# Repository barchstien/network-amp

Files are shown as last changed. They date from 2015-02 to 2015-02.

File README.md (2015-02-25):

# network-amp
PCB including DAC, audio amp, RaspberryPi interface and power supply

<br /><span xmlns:dct="http://purl.org/dc/terms/" property="dct:title">network-amp</span> by <span xmlns:cc="http://creativecommons.org/ns#" property="cc:attributionName">bastienauneau</span> is licensed under a <a rel="license" href="http://creativecommons.org/licenses/by-sa/4.0/">Creative Commons Attribution-ShareAlike 4.0 International License</a>.

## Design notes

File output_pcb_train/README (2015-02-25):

All files have been generated by KiCAD (specified if modified)

For any question, please contact:
Bastien Auneau
bastien.auneau@gmail.com
+33 7 81 13 59 88

## PCB ##
_ audio_pi.drl
    drill file
_ audio_pi-B_Cu.gbr 
_ audio_pi-B_Mask.gbr
_ audio_pi-drl_map.gbr
    drill diameter map (useless ?)
_ audio_pi-Edge_Cuts.gbr
_ audio_pi-F_Cu.gbr
_ audio_pi-F_Mask.gbr
_ audio_pi-F_Paste.gbr
_ audio_pi-F_SilkS.gbr

## ASSEMBLY ##
_ audio_pi-all_position.csv
    smd components position, based on kicad generated "footprint position .pos file"
    joined with BOM file for SUPPLIER and SUPPLIER PART NO. columns
_ audio_pi_BOM.csv
    BOM, ordered by value after generation by kicad

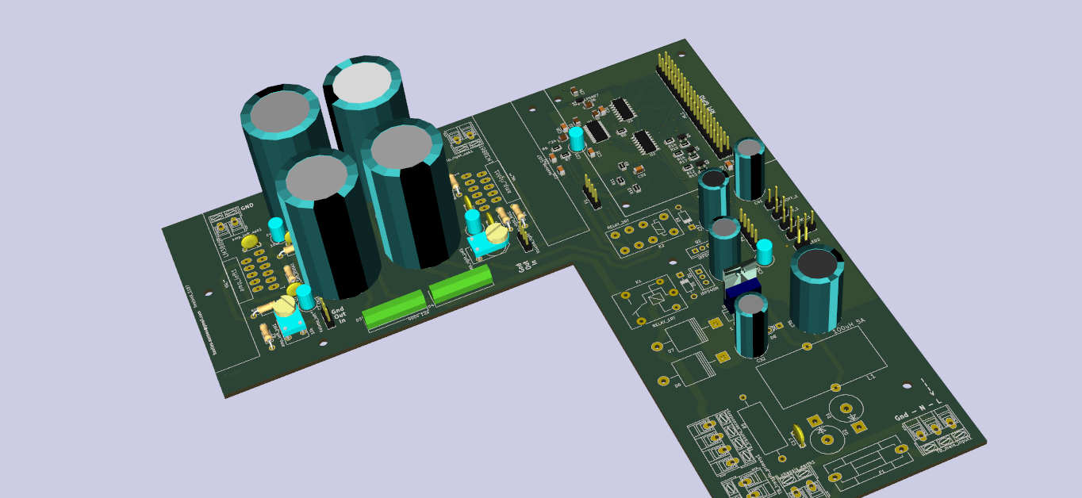
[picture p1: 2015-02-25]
audio_pi_3d.png

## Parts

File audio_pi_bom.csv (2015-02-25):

Reference | Value | Footprint | Datasheet | e44.com | SUPPLIER | SUPPLIER PART NO. | Comment
amp_left1 | LM3886T | lib:TO220-11 |  | LM3886T
U1 | PCM5122 | Housings_SSOP:TSSOP-28_4.4x9.7mm_Pitch0.65mm |  |  | Farnell | 2307931
R2 | 10k | Resistors_ThroughHole:Resistor_Horizontal_RM10mm |  | MA10K0
C8 | 100nf | Capacitors_ThroughHole:Capacitor6MMDiscRM5 |  | CC5100NF
C3 | 100nf | Capacitors_ThroughHole:Capacitor6MMDiscRM5 |  | CC5100NF
C4 | 10uf | Discret:C1V7 |  | CHR10100
C7 | 10uf | Discret:C1V7 |  | CHR10100
amp_left_pot1 | 10k | Discret:RV2X4 |  | CA9V10K
amp_left_spk1 | Terminal_block_2 | Connect:AK300-2 |  | SCREW02BL
C2 | 220pf | Capacitors_ThroughHole:Capacitor6MMDiscRM5 |  | CC5220PF/500
R1 | 1k | Resistors_ThroughHole:Resistor_Horizontal_RM10mm |  | MA1K0
amp_left_Rfdbk1 | 20k | Resistors_ThroughHole:Resistor_Horizontal_RM10mm |  | MA20K0
amp_left_Rin1 | 1k | Resistors_ThroughHole:Resistor_Horizontal_RM10mm |  | MA1K0
R4 | 10k | Resistors_ThroughHole:Resistor_Horizontal_RM10mm |  | MA10K0
C16 | 100nf | Capacitors_ThroughHole:Capacitor6MMDiscRM5 |  | CC5100NF
C11 | 100nf | Capacitors_ThroughHole:Capacitor6MMDiscRM5 |  | CC5100NF
C15 | 10uf | Discret:C1V7 |  | CHR10100
amp_right_pot1 | 10k | Discret:RV2X4 |  | CA9V10K
amp_right_spk1 | Terminal_block_2 | Connect:AK300-2 |  | SCREW02BL
C10 | 220pf | Capacitors_ThroughHole:Capacitor6MMDiscRM5 |  | CC5220PF/500
R3 | 1k | Resistors_ThroughHole:Resistor_Horizontal_RM10mm |  | MA1K0
amp_right_Rfdbk1 | 20k | Resistors_ThroughHole:Resistor_Horizontal_RM10mm |  | MA20K0
amp_right_Rin1 | 1k | Resistors_ThroughHole:Resistor_Horizontal_RM10mm |  | MA1K0
TB_main_input1 | Terminal_block_3 | Connect:AK300-3 |  | SCREW03BL
C17 | 100nf | Capacitors_ThroughHole:Capacitor6MMDiscRM5 |  | CCM100NF
D2 | 400v 6a p6 | Diodes_ThroughHole:Diode_P600_Vertical_KathodeUp |  | P600G
D1 | 400v 6a p6 | Diodes_ThroughHole:Diode_P600_Vertical_KathodeUp |  | P600G
R5 | 10_5W | Resistors_ThroughHole:Resistor_Horizontal_RM25mm |  | vrac
TB_transfo_primary1 | Terminal_block_2 | Connect:AK300-2 |  | SCREW02BL
TB_transfo_secondary1 | Terminal_block_4 | Connect:AK300-4 |  | 2xSCREW02BL
D4 | 400v 12a | Connect:bornier4 |  | KBU12G
D3 | 400v 12a | Connect:bornier4 |  | KBU12G
C18 | 4700uF | Capacitors_ThroughHole:Capacitor26x45RM10 |  | CHR470080-85
C28 | 4700uF | Capacitors_ThroughHole:Capacitor26x45RM10 |  | CHR470080-85
C19 | 4700uF | Capacitors_ThroughHole:Capacitor26x45RM10 |  | CHR470080-85
C29 | 4700uF | Capacitors_ThroughHole:Capacitor26x45RM10 |  | CHR470080-85
U4 | LM2576-5.0 | Pentawatts:Pentawatt_Neutral_Staggered_Verical_TO220-5-T05D |  | LM2576T5
C32 | 100uf | Capacitors_ThroughHole:Capacitor10x21RM5 |  | CHR100100
D8 | 1N5822 | Diodes_ThroughHole:Diode_DO-41_SOD81_Vertical_KathodeUp |  | 1N5822
C35 | 2200uf | Capacitors_ThroughHole:Capacitor16x25RM7.5 |  | CHR220035
L1 | 100uH 5A | lib:inductance |  | HFSECO5/100
U5 | LP5907 | SMD_Packages:SOT-23-5 |  |  | Digikey | 296-38557-1-ND
K2 | RELAY_2RT | lib:Relais_double |  | F3022-5
K1 | RELAY_1RT | lib:Relay_Power |  | F3611-5
Q1 | IRF540N | Discret:TO220_VERT |  | IRF540NPBF
Q2 | IRF540N | Discret:TO220_VERT |  | IRF540NPBF
P2 | Volume_left | Pin_Headers:Pin_Header_Straight_1x03 |  | BTWM3
P3 | Volume_right | Pin_Headers:Pin_Header_Straight_1x03 |  | BTWM3
C37 | 100uf | Capacitors_ThroughHole:Capacitor10x21RM5 |  | CHR100100
D9 | TVS 1500w 400v do201 | Diodes_ThroughHole:Diode_DO-41_SOD81_Horizontal_RM10 |  | 1.5KE400CA
D5 | TVS 1500w 400v do201 | Diodes_ThroughHole:Diode_DO-41_SOD81_Horizontal_RM10 |  | 1.5KE400CA
C27 | 100uf | Capacitors_ThroughHole:Capacitor10x21RM5 |  | CHR100100
D6 | 400v 6a p6 | Diodes_ThroughHole:Diode_P600_Horizontal |  | P600G
D7 | 400v 6a p6 | Diodes_ThroughHole:Diode_P600_Horizontal |  | P600G
F1 | 5A | Fuse_Holders_and_Fuses:Fuseholder5x20_horiz_SemiClosed_Casing10x25mm |  | FUSE/HL*
TB_chassis_earth1 | Terminal_block_2 | Connect:AK300-2 |  | SCREW02BL
C22 | 0.1uf | Capacitors_SMD:C_1206 |  |  | Farnell | 1759361 | PCB Train free component stock
C34 | 1uf | Capacitors_SMD:C_1206 |  |  | Farnell | 1759454 | PCB Train free component stock
C26 | 2.2uf | Capacitors_SMD:C_1206 |  |  | Farnell | 2310423 | PCB Train free component stock
C24 | 2.2uf | Capacitors_SMD:C_1206 |  |  | Farnell | 2310423 | PCB Train free component stock
R6 | 470R | Resistors_SMD:R_1206 |  |  | Farnell | 2129621 | PCB Train free component stock
R7 | 470R | Resistors_SMD:R_1206 |  |  | Farnell | 2129621 | PCB Train free component stock
C20 | 2.2nf | Capacitors_SMD:C_1206 |  |  | Farnell | 1759341 | PCB Train free component stock
C23 | 10uf | Discret:C1V7 |  | CHR10100
C30 | 0.1uf | Capacitors_SMD:C_1206 |  |  | Farnell | 1759361 | PCB Train free component stock
C31 | 0.1uf | Capacitors_SMD:C_1206 |  |  | Farnell | 1759361 | PCB Train free component stock
R8 | 10k | Resistors_SMD:R_1206 |  |  | Farnell | 2129728 | PCB Train free component stock
U2 | IL717 | Housings_SOIC:SOIC-16_3.9x9.9mm_Pitch1.27mm |  |  | Farnell | 9570659
P1 | CONN_01X04 | Pin_Headers:Pin_Header_Straight_1x04 |  | header pin
R10 | 47k | Resistors_SMD:R_1206 |  |  | Farnell | 2129783 | PCB Train free component stock
R9 | 100k | Resistors_SMD:R_1206 |  |  | Farnell | 2129810 | PCB Train free component stock
R11 | 10k | Resistors_SMD:R_1206 |  |  | Farnell | 2129728 | PCB Train free component stock
C33 | 10nf | Capacitors_SMD:C_1206 |  |  | Farnell | 1759350 | PCB Train free component stock
C12 | 10uf | Discret:C1V7 |  | CHR10100
C36 | 1uf | Capacitors_SMD:C_1206 |  |  | Farnell | 1759454 | PCB Train free component stock
C25 | 0.1uf | Capacitors_SMD:C_1206 |  |  | Farnell | 1759361 | PCB Train free component stock
C21 | 2.2nf | Capacitors_SMD:C_1206 |  |  | Farnell | 1759341 | PCB Train free component stock
U3 | IL715 | Housings_SOIC:SOIC-16_3.9x9.9mm_Pitch1.27mm |  |  | Farnell | 9570632
amp_right1 | LM3886T | lib:TO220-11 |  | LM3886T
C9 | 22uf | Capacitors_ThroughHole:Capacitor8x13RM3.8 |  | CHR22100
C1 | 22uf | Capacitors_ThroughHole:Capacitor8x13RM3.8 |  | CHR22100
Q3 | MMBF170 | SMD_Packages:SOT-23 |  |  | Farnell | 9845399
Q4 | MMBF170 | SMD_Packages:SOT-23 |  |  | Farnell | 9845399
Q5 | MMBF170 | SMD_Packages:SOT-23 |  |  | Farnell | 9845399
R12 | 10k | Resistors_SMD:R_1206 |  |  | Farnell | 2129728 | PCB Train free component stock
R13 | 10k | Resistors_SMD:R_1206 |  |  | Farnell | 2129728 | PCB Train free component stock
R14 | 10k | Resistors_SMD:R_1206 |  |  | Farnell | 2129728 | PCB Train free component stock
R15 | 10k | Resistors_SMD:R_1206 |  |  | Farnell | 2129728 | PCB Train free component stock
R17 | 10k | Resistors_SMD:R_1206 |  |  | Farnell | 2129728 | PCB Train free component stock
R16 | 10k | Resistors_SMD:R_1206 |  |  | Farnell | 2129728 | PCB Train free component stock
C38 | 10uf | Discret:C1V7 |  | CHR10100
FAV_1 | CONN_01X02 | Pin_Headers:Pin_Header_Straight_1x02 |  | BTWM2
U6 | LP5907 | SMD_Packages:SOT-23-5 |  |  | Digikey | 296-38557-1-ND
C39 | 1uf | Resistors_SMD:R_1206 |  |  | Farnell | 1759454 | PCB Train free component stock
C40 | 1uf | Resistors_SMD:R_1206 |  |  | Farnell | 1759454 | PCB Train free component stock
ONOFF_1 | CONN_01X02 | Pin_Headers:Pin_Header_Straight_1x02 |  | BTWM2
J8_1 | RPI_B+_J8_header | Pin_Headers:Pin_Header_Straight_2x20
C41 | 100uf | Capacitors_ThroughHole:Capacitor10x21RM5 |  | CHR100100
C42 | 100nf | Capacitors_SMD:C_1206 |  |  | Farnell | 1759361 | PCB Train free component stock
PWM1_1 | CONN_01X02 | Pin_Headers:Pin_Header_Straight_1x02 |  | BTWM2
Q7 | IRF540N | Discret:TO220_VERT |  | IRF540NPBF
LED2 | CONN_01X02 | Pin_Headers:Pin_Header_Straight_1x02 |  | BTWM2
P4 | CONN_01X05 | Pin_Headers:Pin_Header_Straight_1x05
I2C1_1 | CONN_01X04 | Pin_Headers:Pin_Header_Straight_1x04

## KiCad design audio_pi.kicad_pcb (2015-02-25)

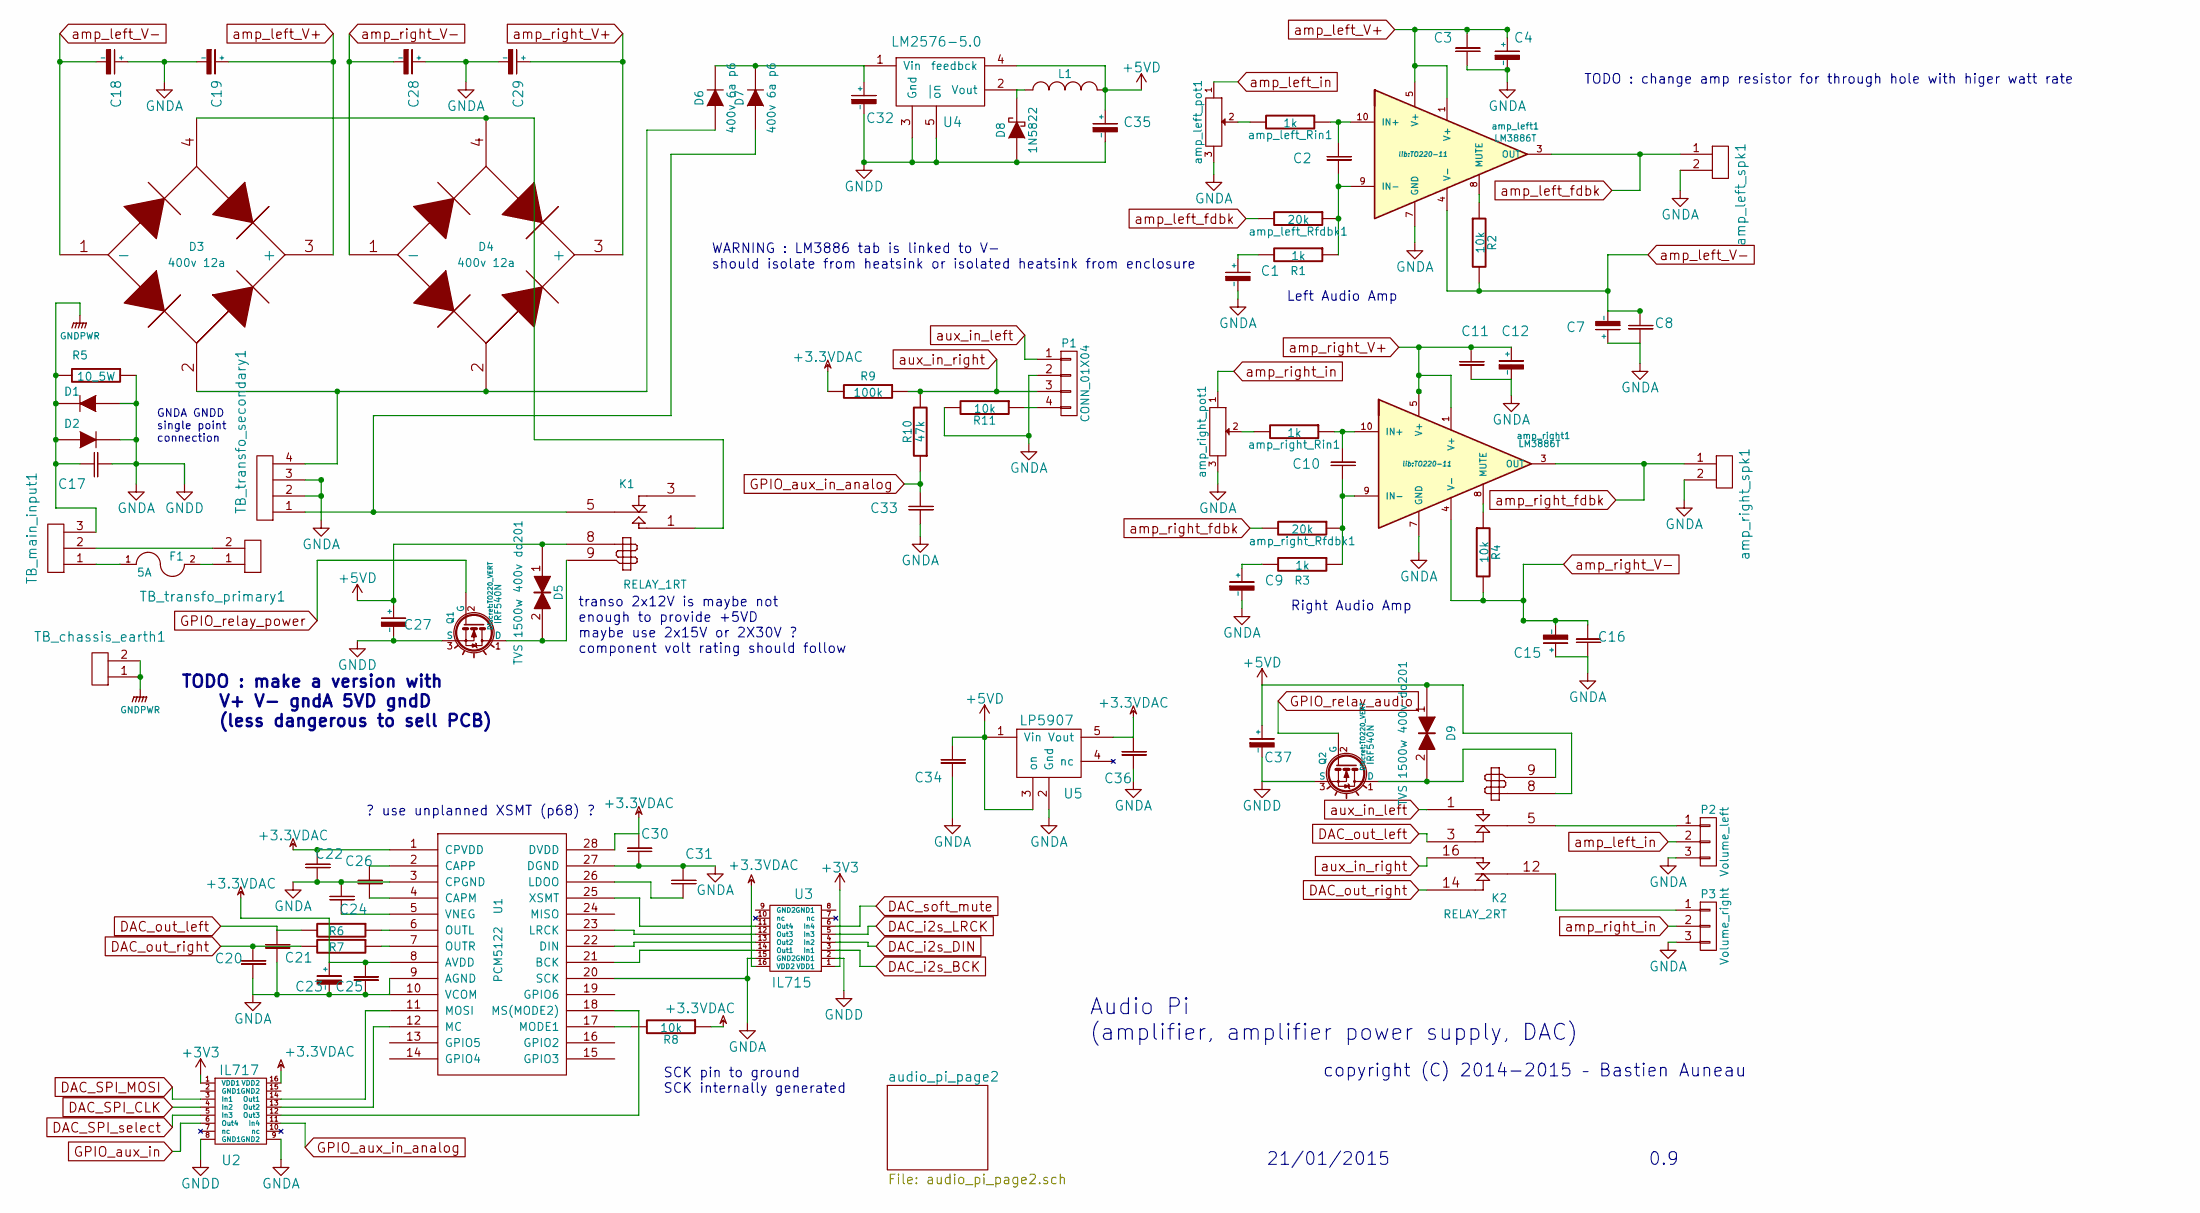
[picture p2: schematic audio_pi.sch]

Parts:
C1, C9: 22uf; Capacitor8x13RM3.8
C2, C10: 220pf; Capacitor6MMDiscRM5
C3, C8, C11, C16, C17: 100nf; Capacitor6MMDiscRM5
C4, C7, C12, C15, C23: 10uf; C1V7
C18, C19, C28, C29: 4700uF; Capacitor26x45RM10
C20, C21: 2.2nf; C_1206
C22, C25, C30, C31: 0.1uf; C_1206
C24, C26: 2.2uf; C_1206
C27, C32, C37: 100uf; Capacitor10x21RM5
C33: 10nf; C_1206
C34, C36: 1uf; C_1206
C35: 2200uf; Capacitor16x25RM7.5
D1, D2: 400v 6a p6; Diode_P600_Vertical_KathodeUp
D3, D4: 400v 12a; bornier4
D5, D9: TVS 1500w 400v do201; Diode_DO-41_SOD81_Horizontal_RM10
D6, D7: 400v 6a p6; Diode_P600_Horizontal
D8: 1N5822; Diode_DO-41_SOD81_Vertical_KathodeUp
F1: 5A; Fuseholder5x20_horiz_SemiClosed_Casing10x25mm
K1: RELAY_1RT; Relay_Power
K2: RELAY_2RT; Relais_double
L1: 100uH 5A; inductance
P1: CONN_01X04; Pin_Header_Straight_1x04
P2: Volume_left; Pin_Header_Straight_1x03
P3: Volume_right; Pin_Header_Straight_1x03
Q1, Q2: IRF540N; TO220_VERT
R1, R3: 1k; Resistor_Horizontal_RM10mm
R2, R4: 10k; Resistor_Horizontal_RM10mm
R5: 10_5W; Resistor_Horizontal_RM25mm
R6, R7: 470R; R_1206
R8, R11: 10k; R_1206
R9: 100k; R_1206
R10: 47k; R_1206
TB_chassis_earth1: Terminal_block_2; AK300-2
TB_main_input1: Terminal_block_3; AK300-3
TB_transfo_primary1: Terminal_block_2; AK300-2
TB_transfo_secondary1: Terminal_block_4; AK300-4
U1: PCM5122; TSSOP-28_4.4x9.7mm_Pitch0.65mm
U2: IL717; SOIC-16_3.9x9.9mm_Pitch1.27mm
U3: IL715; SOIC-16_3.9x9.9mm_Pitch1.27mm
U4: LM2576-5.0; Pentawatt_Neutral_Staggered_Verical_TO220-5-T05D
U5: LP5907; SOT-23-5
amp_left1: LM3886T; TO220-11
amp_left_Rfdbk1: 20k; Resistor_Horizontal_RM10mm
amp_left_Rin1: 1k; Resistor_Horizontal_RM10mm
amp_left_pot1: 10k; RV2X4
amp_left_spk1: Terminal_block_2; AK300-2
amp_right1: LM3886T; TO220-11
amp_right_Rfdbk1: 20k; Resistor_Horizontal_RM10mm
amp_right_Rin1: 1k; Resistor_Horizontal_RM10mm
amp_right_pot1: 10k; RV2X4
amp_right_spk1: Terminal_block_2; AK300-2

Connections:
+3.3VDAC: C22.2, C23.1 (+), C25.2, C30.2, C36.2, R8.1, R9.2, U1.1 (CPVDD), U1.8 (AVDD), U1.28 (DVDD), U2.16 (VDD2), U3.16 (VDD2), U5.5 (Vout)
+3V3: U2.1 (VDD1), U3.1 (VDD1); also elsewhere on the board
+5VD: C27.1 (+), C34.2, C35.1 (+), C37.1 (+), D5.1, D9.1, K1.8, K2.8, L1.2, U4.4 (feedbck), U5.1 (Vin), U5.3 (on); also elsewhere on the board
DAC_SPI_CLK: U2.4 (In2); also elsewhere on the board
DAC_SPI_select: U2.5 (In3); also elsewhere on the board
DAC_i2s_BCK: U3.3 (In1); also elsewhere on the board
DAC_i2s_DIN: U3.4 (In2); also elsewhere on the board
DAC_i2s_LRCK: U3.5 (In3); also elsewhere on the board
DAC_out_left: C21.2, K2.3 (R1), R6.2
DAC_out_right: C20.2, K2.14 (R2), R7.2
DAC_soft_mute: U3.6 (In4); also elsewhere on the board
GNDD: C1.2 (-), C3.1, C4.2 (-), C7.1 (+), C8.1, C9.2 (-), C11.1, C12.2 (-), C15.1 (+), C16.1, C17.2, C18.1 (+), C19.2 (-), C20.1, C21.1, C22.1, C23.2 (-), C24.2, C25.1, C27.2 (-), C28.1 (+), C29.2 (-), C30.1, C31.2, C32.2 (-), C33.1, C34.1, C35.2 (-), C36.1, C37.2 (-), D1.1 (A), D2.2 (K), D8.1 (A), P1.2, P2.3, P3.3, Q1.3 (S), Q2.3 (S), R5.1, R11.2, TB_transfo_secondary1.2, TB_transfo_secondary1.3, U1.3 (CPGND), U1.9 (AGND), U1.10 (VCOM), U1.20 (SCK), U1.27 (DGND), U2.8 (GND1), U2.9 (GND2), U3.2 (GND1), U3.15 (GND2), U4.3 (Gnd), U4.5 (~on), U5.2 (Gnd), amp_left1.7 (GND), amp_left_pot1.3, amp_left_spk1.2, amp_right1.7 (GND), amp_right_pot1.3, amp_right_spk1.2; also elsewhere on the board
GNDPWR: C17.1, D1.2 (K), D2.1 (A), R5.2, TB_chassis_earth1.1, TB_chassis_earth1.2, TB_main_input1.3
GPIO_aux_in: U2.6 (Out4); also elsewhere on the board
GPIO_aux_in_analog: C33.2, R10.1, U2.11 (In4)
GPIO_relay_audio: Q2.2 (G); also elsewhere on the board
GPIO_relay_power: Q1.2 (G); also elsewhere on the board
unnamed: C1.1 (+), R1.2
unnamed: C2.1, R1.1, amp_left1.9 (IN-), amp_left_Rfdbk1.1
unnamed: C2.2, amp_left1.10 (IN+), amp_left_Rin1.1
unnamed: C9.1 (+), R3.2
unnamed: C10.1, R3.1, amp_right1.9 (IN-), amp_right_Rfdbk1.1
unnamed: C10.2, amp_right1.10 (IN+), amp_right_Rin1.1
unnamed: C24.1, U1.5 (VNEG)
unnamed: C26.1, U1.4 (CAPM)
unnamed: C26.2, U1.2 (CAPP)
unnamed: C31.1, U1.26 (LDOO)
unnamed: C32.1 (+), D6.2 (K), D7.2 (K), U4.1 (Vin)
unnamed: D3.2, D4.2, D6.1 (A), TB_transfo_secondary1.4
unnamed: D3.4, D4.4, K1.1 (T1)
unnamed: D5.2, K1.9, Q1.1 (D)
unnamed: D7.1 (A), K1.5 (C1), TB_transfo_secondary1.1
unnamed: D8.2 (K), L1.1, U4.2 (Vout)
unnamed: D9.2, K2.9, Q2.1 (D)
unnamed: F1.1, TB_main_input1.1
unnamed: F1.2, TB_transfo_primary1.1
unnamed: K2.5 (C1), P2.1
unnamed: K2.12 (C2), P3.1
unnamed: P1.4, R11.1
unnamed: R2.1, amp_left1.8 (MUTE)
unnamed: R4.1, amp_right1.8 (MUTE)
unnamed: R6.1, U1.6 (OUTL)
unnamed: R7.1, U1.7 (OUTR)
unnamed: R8.2, U1.17 (MODE1)
unnamed: TB_main_input1.2, TB_transfo_primary1.2
unnamed: U1.11 (MOSI), U2.14 (Out1)
unnamed: U1.12 (MC), U2.13 (Out2)
unnamed: U1.18 (MS(MODE2)), U2.12 (Out3)
unnamed: U1.21 (BCK), U3.14 (Out1)
unnamed: U1.22 (DIN), U3.13 (Out2)
unnamed: U1.23 (LRCK), U3.12 (Out3)
unnamed: U1.25 (XSMT), U3.11 (Out4)
unnamed: amp_left_Rin1.2, amp_left_pot1.2
unnamed: amp_right_Rin1.2, amp_right_pot1.2
amp_left_V+: C3.2, C4.1 (+), C19.1 (+), D3.3 (+), amp_left1.1 (V+), amp_left1.5 (V+)
amp_left_V-: C7.2 (-), C8.2, C18.2 (-), D3.1 (-), R2.2, amp_left1.4 (V-)
amp_left_fdbk: amp_left1.3 (OUT), amp_left_Rfdbk1.2, amp_left_spk1.1
amp_left_in: P2.2, amp_left_pot1.1
amp_right_V+: C11.2, C12.1 (+), C29.1 (+), D4.3 (+), amp_right1.1 (V+), amp_right1.5 (V+)
amp_right_V-: C15.2 (-), C16.2, C28.2 (-), D4.1 (-), R4.2, amp_right1.4 (V-)
amp_right_fdbk: amp_right1.3 (OUT), amp_right_Rfdbk1.2, amp_right_spk1.1
amp_right_in: P3.2, amp_right_pot1.1
aux_in_left: K2.1 (T1), P1.1
aux_in_right: K2.16 (T2), P1.3, R9.1, R10.2
screen_SPI_MOSI: U2.3 (In1); also elsewhere on the board

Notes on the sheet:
Left Audio Amp
Right Audio Amp
Audio Pi (amplifier, amplifier power supply, DAC)
21/01/2015
0.9
copyright (C) 2014-2015 – Bastien Auneau
transo 2x12V is maybe not enough to provide +5VD maybe use 2x15V or 2X30V ? component volt rating should follow
GNDA GNDD single point connection
WARNING : LM3886 tab is linked to V- should isolate from heatsink or isolated heatsink from enclosure
SCK pin to ground SCK internally generated
? use unplanned XSMT (p68) ?
TODO : make a version with V+ V- gndA 5VD gndD (less dangerous to sell PCB)
TODO : change amp resistor for through hole with higer watt rate

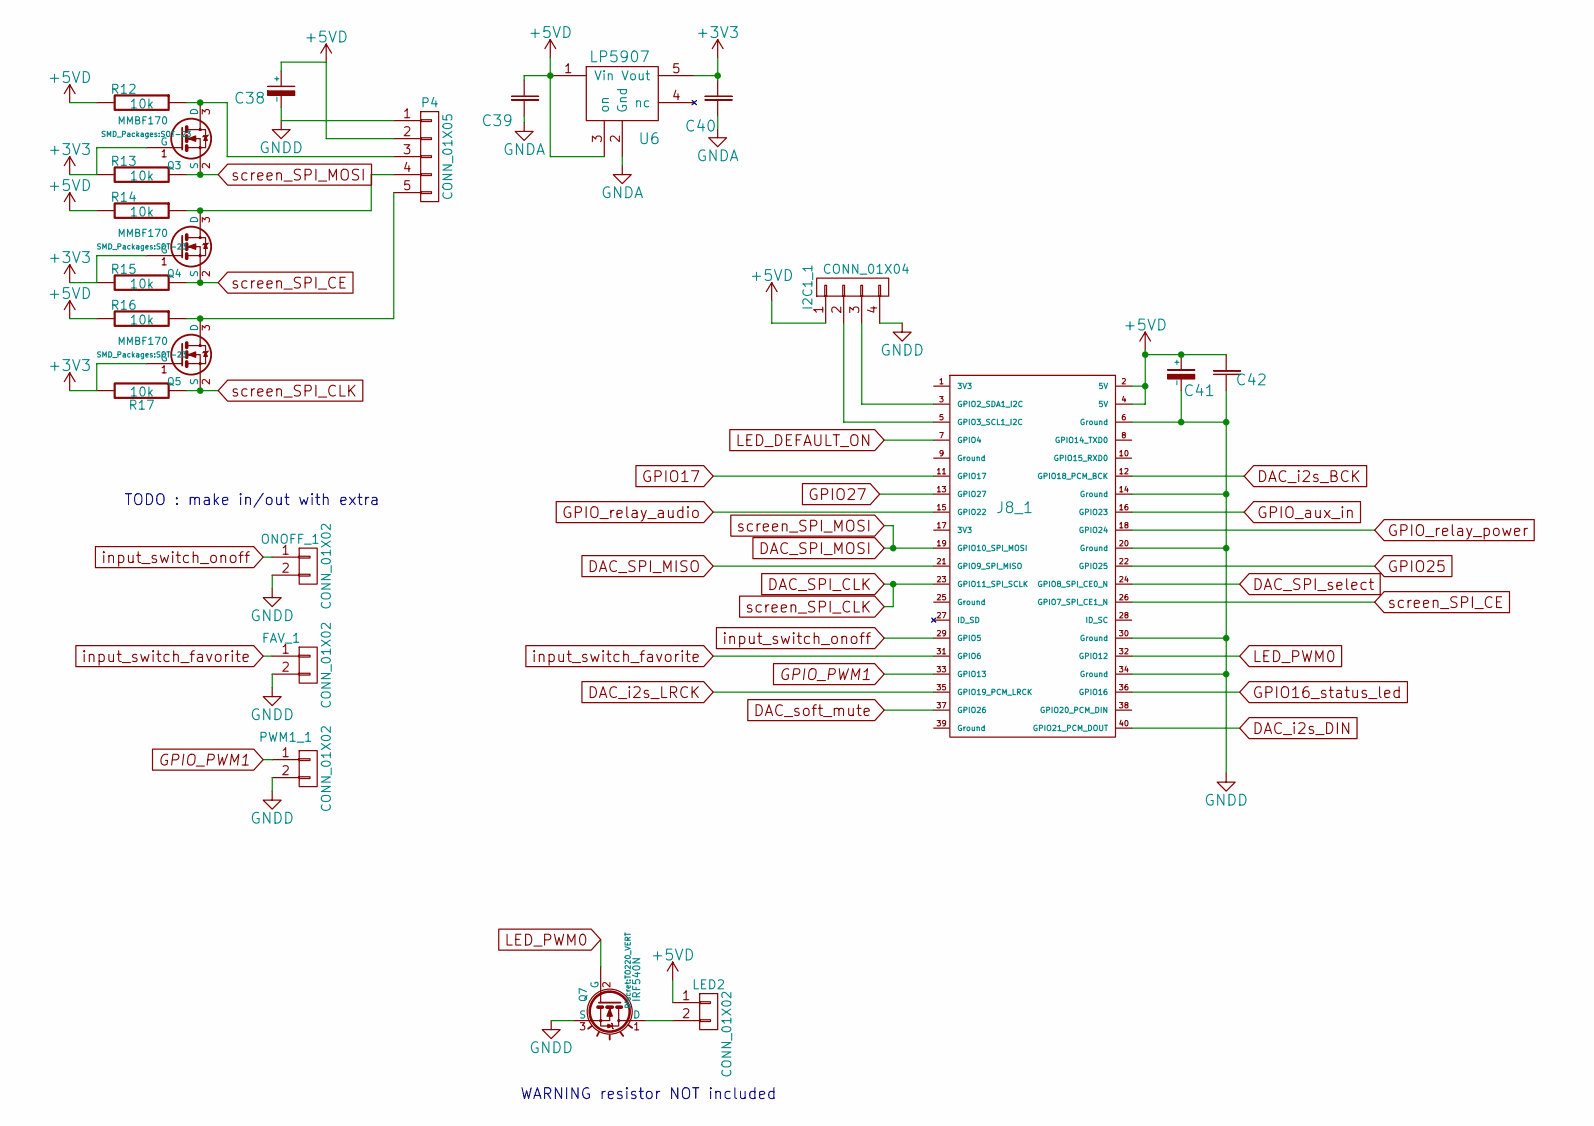
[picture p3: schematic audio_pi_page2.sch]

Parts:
C38: 10uf; C1V7
C39, C40: 1uf; R_1206
C41: 100uf; Capacitor10x21RM5
C42: 100nf; C_1206
FAV_1: CONN_01X02; Pin_Header_Straight_1x02
I2C1_1: CONN_01X04; Pin_Header_Straight_1x04
J8_1: RPI_B+_J8_header; Pin_Header_Straight_2x20
LED2: CONN_01X02; Pin_Header_Straight_1x02
ONOFF_1: CONN_01X02; Pin_Header_Straight_1x02
P4: CONN_01X05; Pin_Header_Straight_1x05
PWM1_1: CONN_01X02; Pin_Header_Straight_1x02
Q3, Q4, Q5: MMBF170; SOT-23
Q7: IRF540N; TO220_VERT
R12, R13, R14, R15, R16, R17: 10k; R_1206
U6: LP5907; SOT-23-5

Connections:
+3V3: C40.2, Q3.1 (G), Q4.1 (G), Q5.1 (G), R13.2, R15.2, R17.2, U6.5 (Vout); also elsewhere on the board
+5VD: C38.1 (+), C39.2, C41.1 (+), C42.2, I2C1_1.1, J8_1.2 (5V), J8_1.4 (5V), LED2.1, P4.2, R12.2, R14.2, R16.2, U6.1 (Vin), U6.3 (on); also elsewhere on the board
DAC_SPI_CLK: J8_1.23 (GPIO11_SPI_SCLK), Q5.2 (S), R17.1; also elsewhere on the board
DAC_SPI_MISO: J8_1.21 (GPIO9_SPI_MISO)
DAC_SPI_select: J8_1.24 (GPIO8_SPI_CE0_N); also elsewhere on the board
DAC_i2s_BCK: J8_1.12 (GPIO18_PCM_BCK); also elsewhere on the board
DAC_i2s_DIN: J8_1.40 (GPIO21_PCM_DOUT); also elsewhere on the board
DAC_i2s_LRCK: J8_1.35 (GPIO19_PCM_LRCK); also elsewhere on the board
DAC_soft_mute: J8_1.37 (GPIO26); also elsewhere on the board
GNDD: C38.2 (-), C39.1, C40.1, C41.2 (-), C42.1, FAV_1.2, I2C1_1.4, J8_1.6 (Ground), J8_1.14 (Ground), J8_1.20 (Ground), J8_1.30 (Ground), J8_1.34 (Ground), ONOFF_1.2, P4.1, PWM1_1.2, Q7.3 (S), U6.2 (Gnd); also elsewhere on the board
GPIO16_status_led: J8_1.36 (GPIO16)
GPIO17: J8_1.11 (GPIO17)
GPIO25: J8_1.22 (GPIO25)
GPIO27: J8_1.13 (GPIO27)
GPIO_PWM1: J8_1.33 (GPIO13), PWM1_1.1
GPIO_aux_in: J8_1.16 (GPIO23); also elsewhere on the board
GPIO_relay_audio: J8_1.15 (GPIO22); also elsewhere on the board
GPIO_relay_power: J8_1.18 (GPIO24); also elsewhere on the board
LED_DEFAULT_ON: J8_1.7 (GPIO4)
LED_PWM0: J8_1.32 (GPIO12), Q7.2 (G)
unnamed: I2C1_1.2, J8_1.5 (GPIO3_SCL1_I2C)
unnamed: I2C1_1.3, J8_1.3 (GPIO2_SDA1_I2C)
unnamed: LED2.2, Q7.1 (D)
unnamed: P4.3, Q3.3 (D), R12.1
unnamed: P4.4, Q4.3 (D), R14.1
unnamed: P4.5, Q5.3 (D), R16.1
input_switch_favorite: FAV_1.1, J8_1.31 (GPIO6)
input_switch_onoff: J8_1.29 (GPIO5), ONOFF_1.1
screen_SPI_CE: J8_1.26 (GPIO7_SPI_CE1_N), Q4.2 (S), R15.1
screen_SPI_MOSI: J8_1.19 (GPIO10_SPI_MOSI), Q3.2 (S), R13.1; also elsewhere on the board

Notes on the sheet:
TODO : make in/out with extra
WARNING resistor NOT included

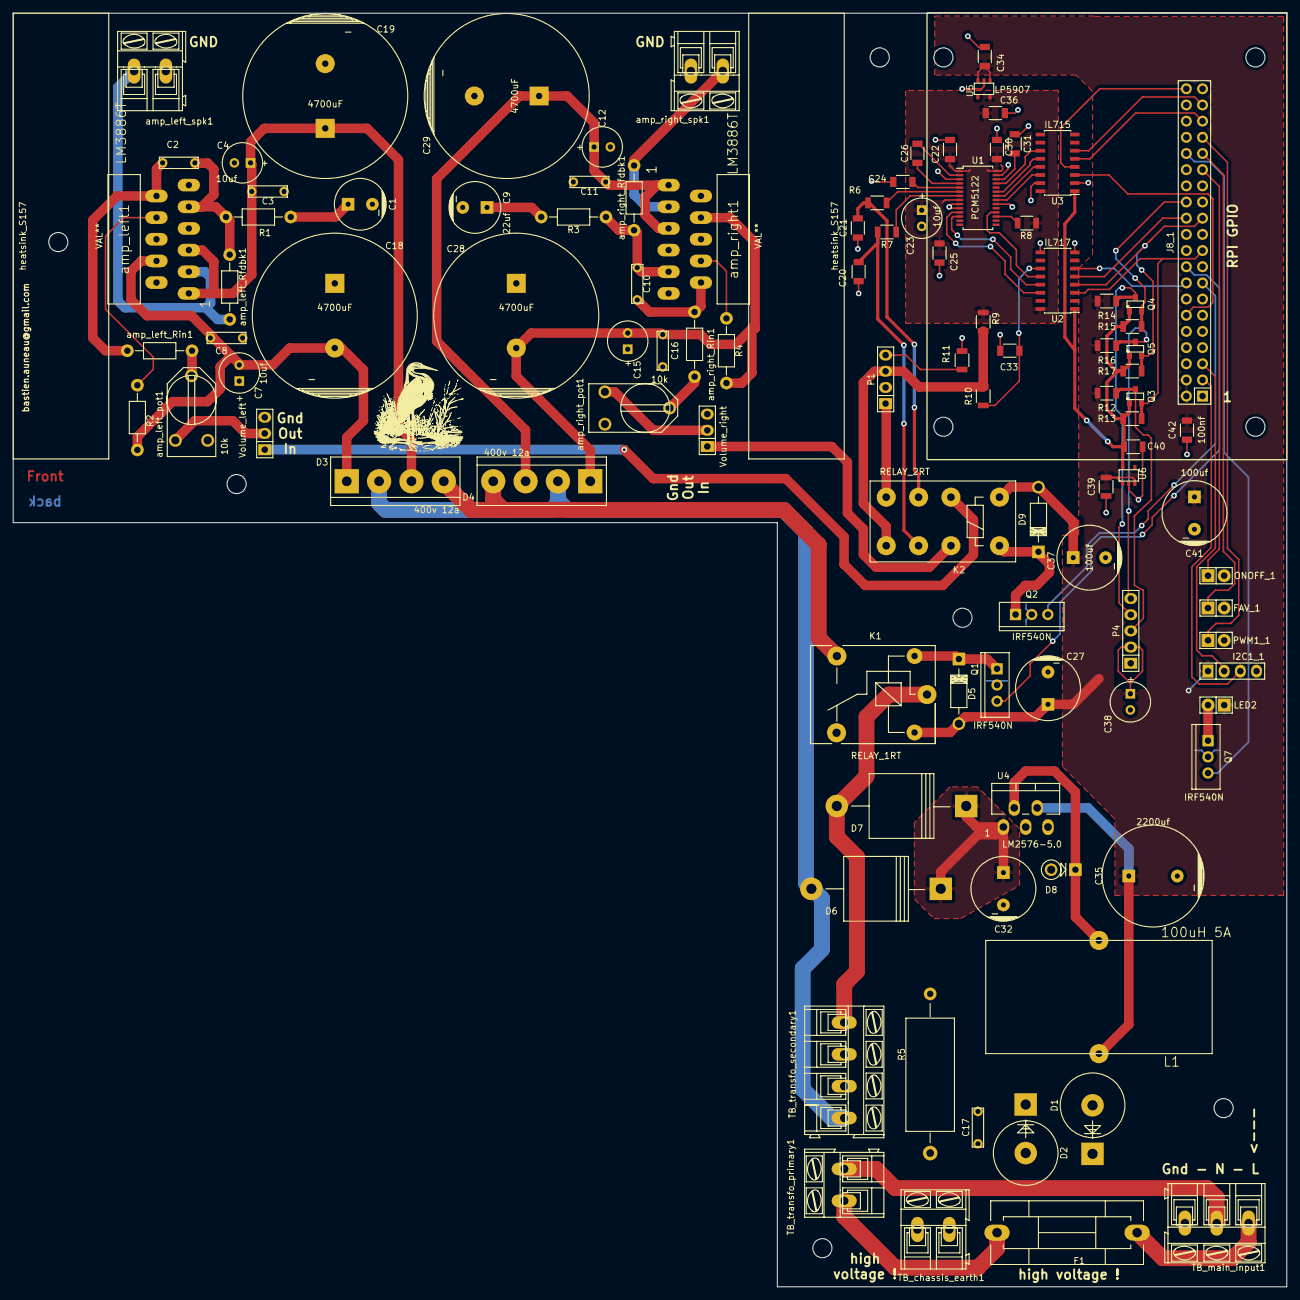
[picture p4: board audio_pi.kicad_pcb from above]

Board: 2 copper layers, 200.0 x 200.0 mm, 116 parts (0 on the bottom side), 76 nets.

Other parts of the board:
MountingHole_3mm, MountingHole_3mm#2, MountingHole_3mm#3, MountingHole_3mm#4, MountingHole_3mm#5, MountingHole_3mm#6, MountingHole_3mm#7, MountingHole_3mm#8, MountingHole_3mm#9, MountingHole_3mm#10: VAL**; MountingHole_3mm
heatsink_S157, heatsink_S157#2: VAL**; heatsink_S157

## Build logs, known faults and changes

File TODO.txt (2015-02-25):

_ last check schematic... done
_ last check pcb... done
_ re-generate layers, drill, BOM, assembly coordinate
_ last check generated files

_ platform to promote, kickstarter linked
    just do it on kickstarter page, take example o, xisting projects, show past projects, list challenges, present team

_ 3.3VDAC from amp v+ ??  NO !

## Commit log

2015-02-25 first upload of project
    [audio_pi-all (copy).ods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]
2015-02-25 cleaned up, checked validity
    [audio_pi-all (copy).ods]
